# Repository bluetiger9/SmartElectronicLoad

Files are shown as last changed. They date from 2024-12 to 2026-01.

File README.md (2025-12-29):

# SmartElectronicLoad
A smart electronic load

## Component Selection

1. Current Sense Amplifier OpAmp:
   - amplifies the voltage drop from the current sense resistors
   - low input offset (<=1mV, lower is better) - offset is amplified with the same amount as the sense current
   - high gain bandwidth product (>=5-10MHz, higher is better) - can limit the overall bandwidth of the load - for ex. 5MHz GBP with 10x amplification results in a 0.5Mhz effective bandwidth
   - input and output must go down to negative rail (0V)
   - input and output may not go up to the positive rail (3V3/12V) - in this case current range is reduced according to the upper limits
   - supply: 0-3V3 (or 0-12V)

2. Load Set OpAmp:
   - controls the gate of the load MOSFETs
   - input and output must go down to the negative rail (0V)
   - gain bandwidth product (>=1MHz) - can limit the overall bandwidth of the load
   - supply: 0-12V

3. Voltage Sense Buffer / Current Sense Buffer OpAmps
   - acts as a buffer for the voltage sense signals
   - input and output must go down to the negative rail (0V)
   - input and output may not go up to the positive rail (3V3/12V) - in this case voltage / current sense ranges are reduces accordingly
   - supply: 0-3V3 (or 0-12V)

4. DAC Buffer OpAmp
   - acts as a buffer for the DAC output
   - input and output must go down to the negative rail (0V)
   - input and output may not go up to the positive rail (3V3/12V) - in this case current range is reduced according to the upper limits
   - supply: 0-3V3 (or 0-12V)

5. MOSFET-s
   - acts as the active dissipates power element
   - N-channel MOSFET in TO-247 or TO-220 package
   - thermal resistance (lower is better) drive heat dissipation capacity
   - switching speed can affect the overall load bandwidth
   - drain source voltage limits the maximum voltage of the load
   - ON state resistance limits the maximum current at low voltages
   - can be in isolated or non-isolated package - non-isolated need additional parts to avoid exposing the load voltage on the heat sink

6. Current Sense Resistor
   - used to measure the current dissipated by the load
   - should be in the range of 5mV-100mΩ - resistor value in combination with multiplication factor gives the current range of the load - ex. 10mΩ + 10x (@3.3V) results in a 0-33A range (per channel)
   - SMD-2512 package
   - two resistors can be placed in parallel to the lower heat dissipation (which causes drift)

7. ESP32 SoC
   - the "brain" of the load
   - ESP32-S3-WROOM-1 modules (or ESP32-S2-SOLO-2, not recommended as it only has one core, and the built in DAC is no longer used)
   - 4MB+ flash, optional PSRAM (Quad SPI only - Octal SPI variants disable some GPIO pins)

## Bandwidth / Stability Tunning:
1. C1/R9 (and C2/R10) sets the overall bandwidth of the load
   - ex. 330Ω with 4.7nF results in a bandwidth of a ~100kHz
   - bandwidth can be increased by changing C1/C2 (or R9/R10) - ex 1nF achieves a bandwidth ~480kHz
     (*note: the current sense and load set OpAmps must keep up)

2. R65 (and R69) sets the MOSFETs gate current
   - default value is 10Ω
   - in case of oscillations, changing this resistor to a higher (ex. 47Ω) or lower (?) value (ex. 1Ω) may help stabilizing the load

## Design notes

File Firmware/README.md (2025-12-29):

# Smart Electronic Load - Firmware

The firmware of the Smart Electronic Load is based on PlatformIO. It uses the ESP32 cores from pioarduino.

Features:
- RTOS based control loop
- Continuous ADC reads
- Web Server with API, and a simple UI
- OTA updates
- etc.

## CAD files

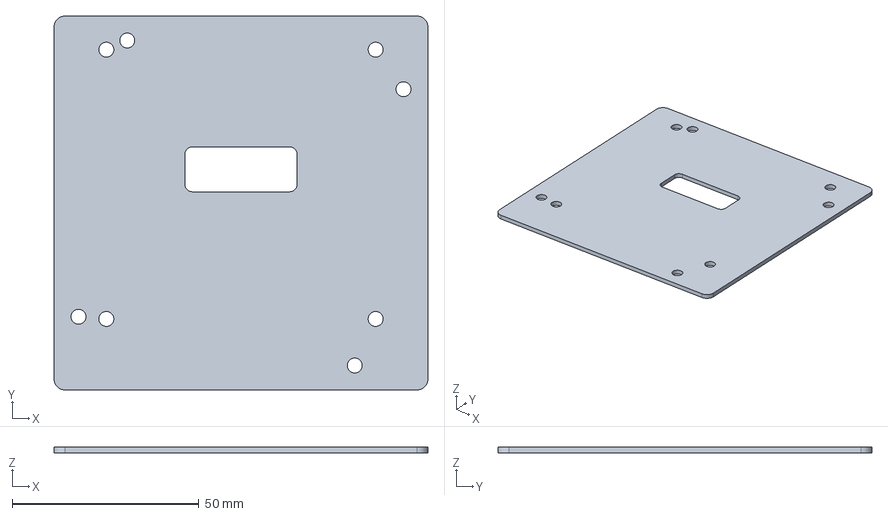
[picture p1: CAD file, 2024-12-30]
FreeCAD/ElectronicLoad.FCStd
100.0 x 100.0 x 1.60 mm

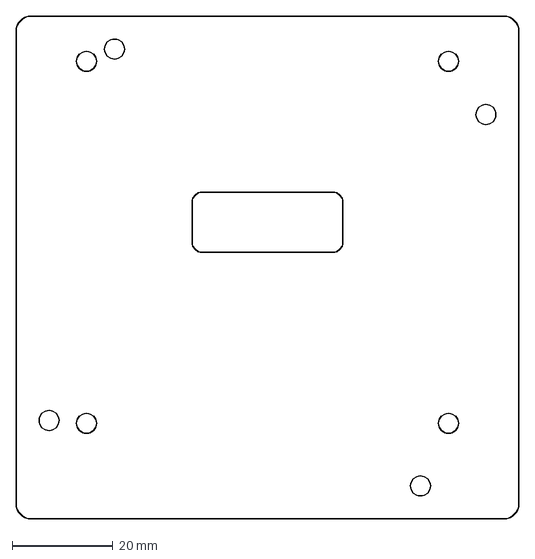
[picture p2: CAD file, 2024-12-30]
FreeCAD/ElectronicLoad-Outline.dxf
100.0 x 100.0 mm

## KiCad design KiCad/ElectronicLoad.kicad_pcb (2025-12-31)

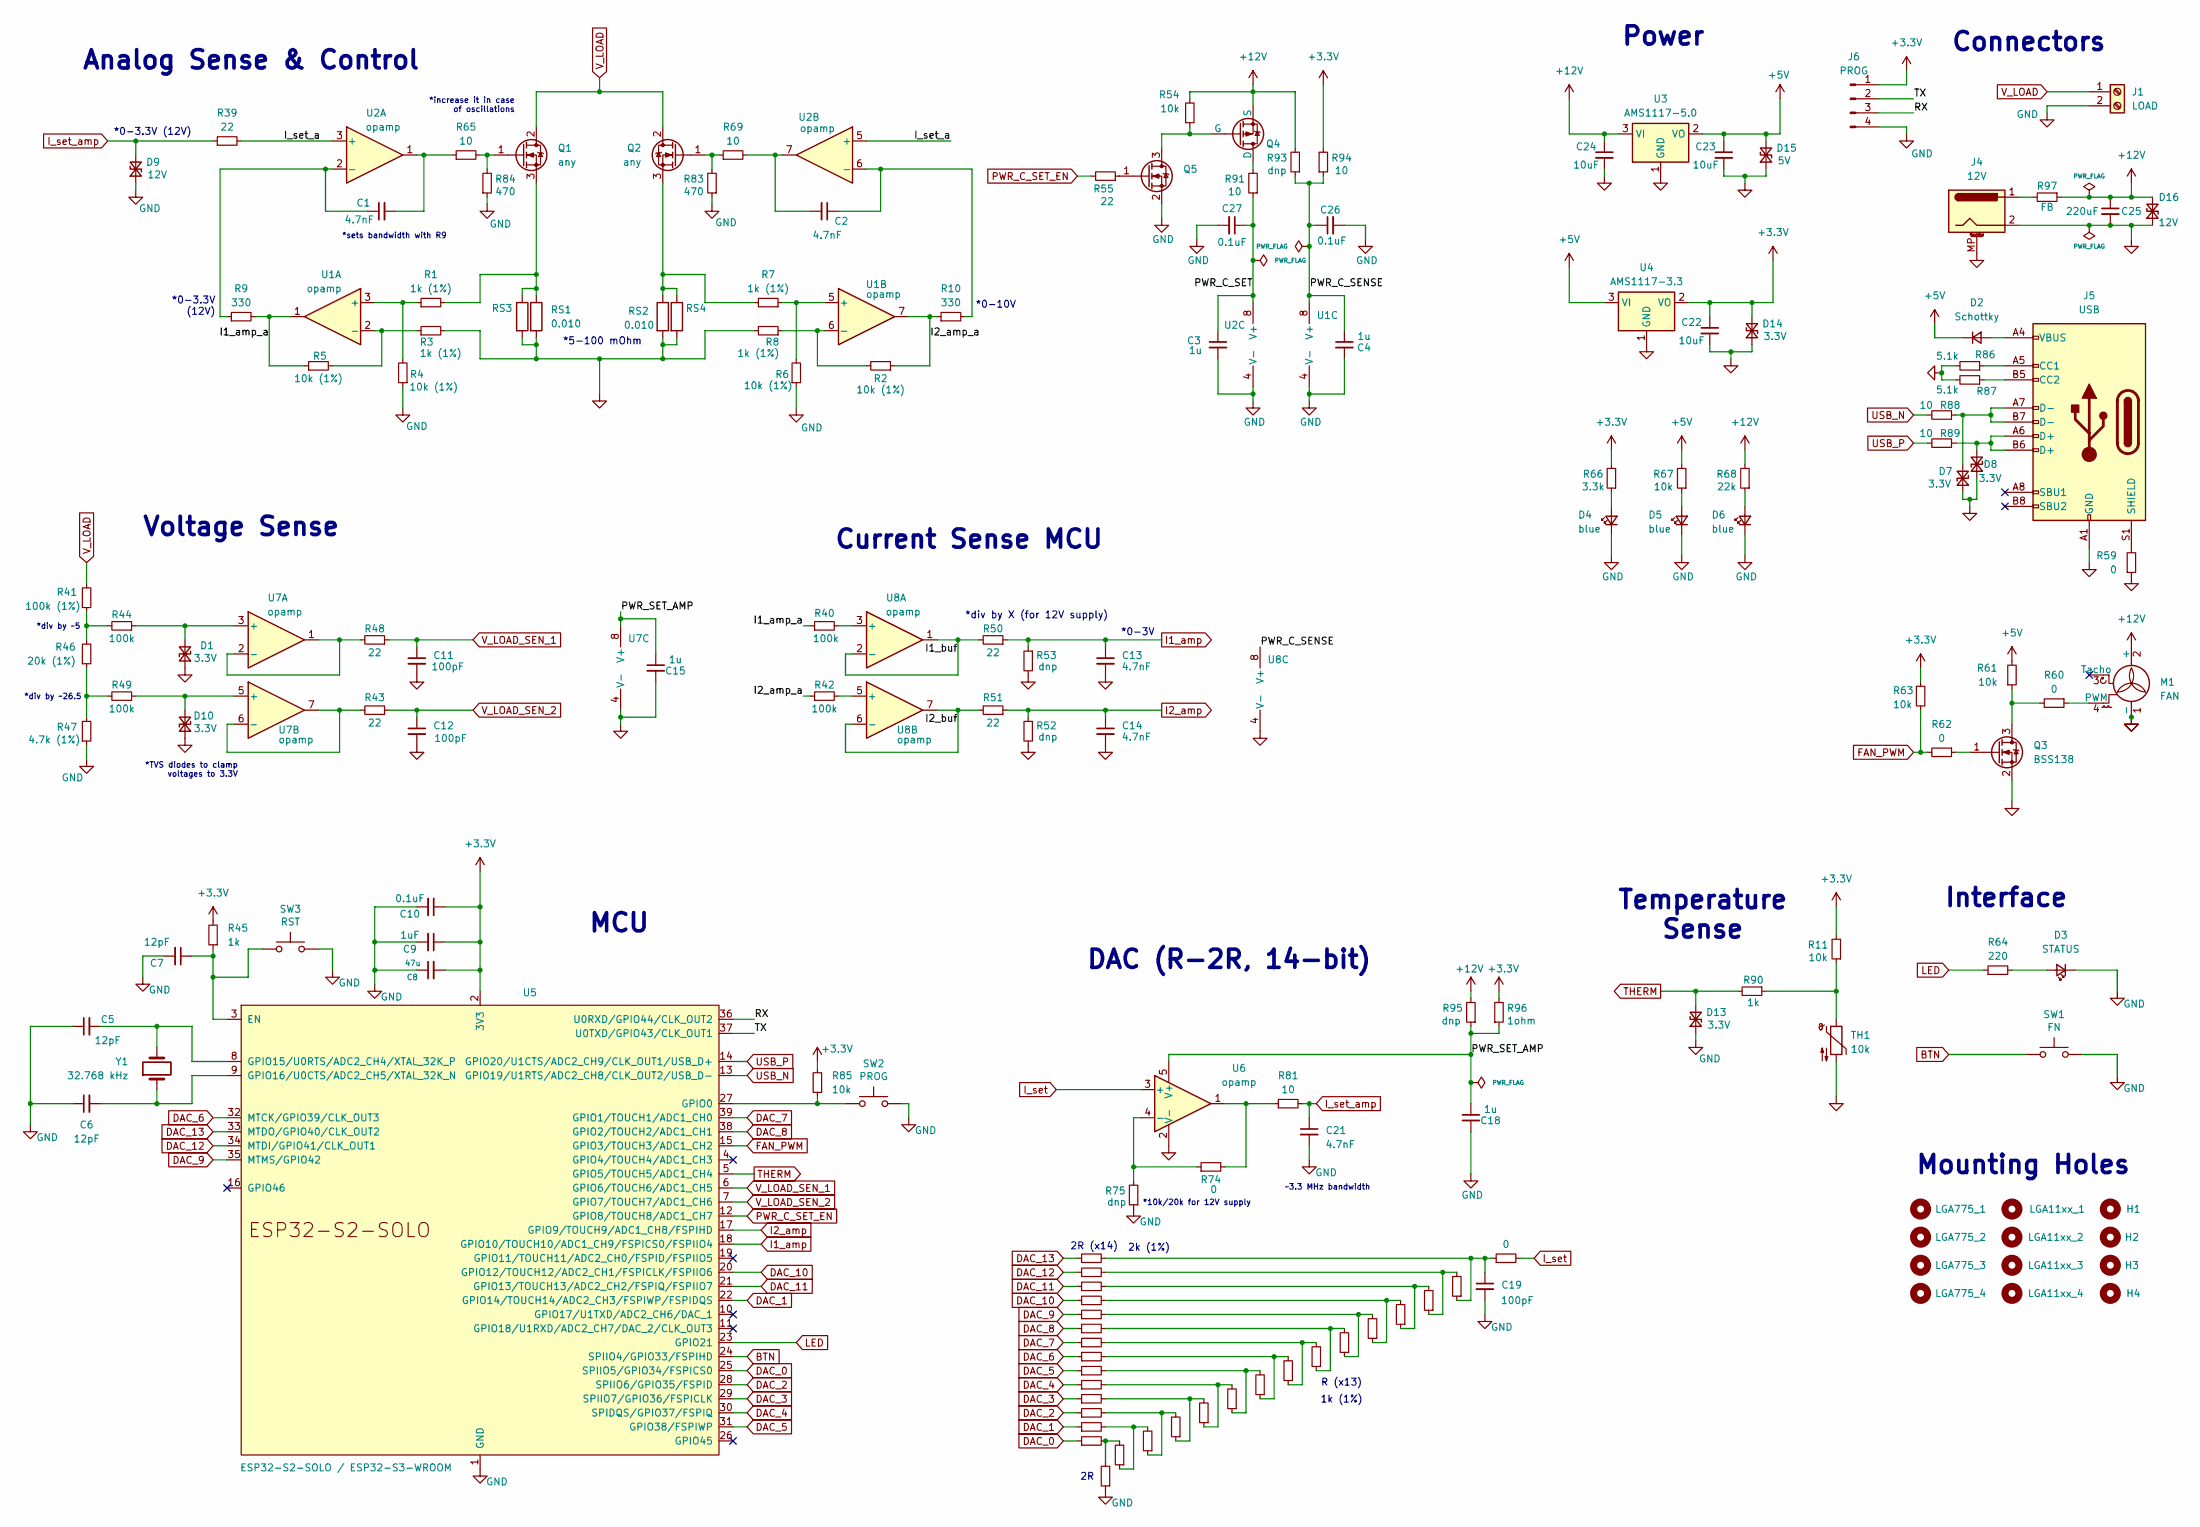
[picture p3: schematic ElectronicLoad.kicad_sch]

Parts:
C1, C2, C13, C14, C21: 4.7nF; C_0603_1608Metric
C3, C4, C15, C18: 1u; C_0603_1608Metric
C5, C6: 12pF; C_0603_1608Metric
C7: 12pF; C_0805_2012Metric
C8: 47u; C_0805_2012Metric
C9: 1uF; C_0805_2012Metric
C10, C26, C27: 0.1uF; C_0805_2012Metric
C11, C12, C19: 100pF; C_0603_1608Metric
C22, C23, C24: 10uF; C_0805_2012Metric
C25: 220uF; C_Elec_6.3x7.7
D1, D7, D8, D10, D13: 3.3V; D_SOD-323_HandSoldering
D2: Schottky; D_SOD-123
D3: STATUS; LED_0805_2012Metric
D4, D5, D6: blue; LED_0805_2012Metric
D9: 12V; D_SOD-323_HandSoldering
D14: 3.3V; D_SOD-123
D15: 5V; D_SOD-123
D16: 12V; D_SOD-123
H1, H2, H3, H4: MountingHole; MountingHole_4.3mm_M4
J1: LOAD; Terminal-Block-7-screw
J4: 12V; BarrelJack_Horizontal
J5: USB; USB_C_Receptacle_G-Switch_GT-USB-7010ASV
J6: PROG; PinHeader_1x04_P2.54mm_Vertical
LGA11xx_1, LGA11xx_2, LGA11xx_3, LGA11xx_4, LGA775_1, LGA775_2, LGA775_3, LGA775_4: MountingHole; MountingHole_4mm
M1: FAN; FanPinHeader_1x04_P2.54mm_Vertical
Q1, Q2: any; TO-247-220
Q3, Q5: BSS138; SOT-23
Q4: PMOS; SOT-23
R1, R3, R7, R8, R25, R26, R27, R28, R29, R30, R31, R32, R33, R34, R35, R36, R37: 1k (1%); R_0603_1608Metric
R2, R4, R5, R6: 10k (1%); R_0603_1608Metric
R9, R10: 330; R_0603_1608Metric
R11, R54, R61, R63, R67, R85: 10k; R_0805_2012Metric
R12, R13, R14, R15, R16, R17, R18, R19, R20, R21, R22, R23, R24, R38, R201: 2k (1%); R_0603_1608Metric
R39, R43, R48, R50, R51: 22; R_0603_1608Metric
R40, R42, R44, R49: 100k; R_0603_1608Metric
R41: 100k (1%); R_0603_1608Metric
R45, R90: 1k; R_0805_2012Metric
R46: 20k (1%); R_0603_1608Metric
R47: 4.7k (1%); R_0603_1608Metric
R52, R53, R75: dnp; R_0603_1608Metric
R55: 22; R_0805_2012Metric
R59, R60, R62: 0; R_0805_2012Metric
R64: 220; R_0805_2012Metric
R65, R69, R81, R88, R89: 10; R_0603_1608Metric
R66: 3.3k; R_0805_2012Metric
R68: 22k; R_0805_2012Metric
R70, R74: 0; R_0603_1608Metric
R83, R84: 470; R_0603_1608Metric
R86, R87: 5.1k; R_0603_1608Metric
R91, R94: 10; R_0805_2012Metric
R93, R95: dnp; R_0805_2012Metric
R96: 1ohm; R_0805_2012Metric
R97: FB; R_0805_2012Metric
RS1, RS2: 0.010; R_2512_6332Metric
RS3, RS4: 0.001; R_2512_6332Metric
SW1: FN; SW_SPST_TL3342
SW2: PROG; SW_SPST_TL3342
SW3: RST; SW_SPST_TL3342
TH1: 10k; PinHeader_1x02_P2.00mm_Vertical
U1, U2, U7, U8: opamp; SOIC-8_3.9x4.9mm_P1.27mm
U3: AMS1117-5.0; SOT-223-3_TabPin2
U4: AMS1117-3.3; SOT-223-3_TabPin2
U5: ESP32-S2-SOLO / ESP32-S3-WROOM; ESP32-S2-SOLO
U6: opamp; SOT-23-5
Y1: 32.768 kHz; Crystal_SMD_3215-2Pin_3.2x1.5mm

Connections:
+3.3V: C8.2, C9.1, C10.1, C22.1, D14.2 (A2), J6.1, R11.2, R45.2, R63.1, R66.2, R85.2, R94.2, R96.2, U4.2 (VO), U5.2 (3V3)
+5V: C23.1, D2.1 (K), D15.2 (A2), R61.2, R67.2, U3.2 (VO), U4.3 (VI)
+12V: C24.1, C25.1, D16.2 (A2), M1.2 (+), Q4.3 (S), R54.2, R68.2, R93.2, R95.2, R97.1, U3.3 (VI)
/I1_amp_a: R5.1, R9.2, R40.1, U1.1
/I1_buf: R50.2, U8.1, U8.2 (-)
/I2_amp_a: R2.1, R10.1, R42.1, U1.7
/I2_buf: R51.2, U8.6 (-), U8.7
/I_set_a: R39.2, U2.3 (+), U2.5 (+)
/PWR_C_SENSE: C4.1, C26.1, R93.1, R94.1, U1.8 (V+), U8.8 (V+)
/PWR_C_SET: C3.1, C27.1, R91.1, U2.8 (V+)
/PWR_SET_AMP: C15.1, C18.1, R95.1, R96.1, U6.5 (V+), U7.8 (V+)
/RX: J6.3, U5.36 (U0RXD/GPIO44/CLK_OUT2)
/TX: J6.2, U5.37 (U0TXD/GPIO43/CLK_OUT1)
BTN: SW1.1, U5.24 (SPIIO4/GPIO33/FSPIHD)
DAC_0: R24.1, U5.25 (SPIIO5/GPIO34/FSPICS0)
DAC_1: R23.1, U5.22 (GPIO14/TOUCH14/ADC2_CH3/FSPIWP/FSPIDQS)
DAC_2: R22.1, U5.28 (SPIIO6/GPIO35/FSPID)
DAC_3: R21.1, U5.29 (SPIIO7/GPIO36/FSPICLK)
DAC_4: R20.1, U5.30 (SPIDQS/GPIO37/FSPIQ)
DAC_5: R19.1, U5.31 (GPIO38/FSPIWP)
DAC_6: R18.1, U5.32 (MTCK/GPIO39/CLK_OUT3)
DAC_7: R17.1, U5.39 (GPIO1/TOUCH1/ADC1_CH0)
DAC_8: R16.1, U5.38 (GPIO2/TOUCH2/ADC1_CH1)
DAC_9: R15.1, U5.35 (MTMS/GPIO42)
DAC_10: R14.1, U5.20 (GPIO12/TOUCH12/ADC2_CH1/FSPICLK/FSPIIO6)
DAC_11: R13.1, U5.21 (GPIO13/TOUCH13/ADC2_CH2/FSPIQ/FSPIIO7)
DAC_12: R12.1, U5.34 (MTDI/GPIO41/CLK_OUT1)
DAC_13: R201.1, U5.33 (MTDO/GPIO40/CLK_OUT2)
FAN_PWM: R62.2, R63.2, U5.15 (GPIO3/TOUCH3/ADC1_CH2)
GND: C3.2, C4.2, C5.1, C6.1, C7.2, C8.1, C9.2, C10.2, C11.2, C12.2, C13.2, C14.2, C15.2, C18.2, C19.2, C21.2, C22.2, C23.2, C24.2, C25.2, C26.2, C27.2, D1.1 (A1), D3.1 (K), D4.1 (K), D5.1 (K), D6.1 (K), D7.1 (A1), D8.1 (A1), D9.1 (A1), D10.1 (A1), D13.1 (A1), D14.1 (A1), D15.1 (A1), D16.1 (A1), J1.2, J4.2, J4.MP (MountPin), J5.A1 (GND), J5.A12 (GND), J5.B1 (GND), J5.B12 (GND), J6.4, M1.1 (-), Q3.2 (S), Q5.2 (S), R3.2, R4.1, R6.1, R8.2, R38.1, R47.1, R52.2, R53.2, R59.1, R75.1, R83.1, R84.1, R86.2, R87.2, RS1.2, RS2.2, RS3.2, RS4.2, SW1.2, SW2.2, SW3.2, TH1.2, U1.4 (V-), U2.4 (V-), U3.1 (GND), U4.1 (GND), U5.1 (GND), U5.40 (GND), U5.41 (GND), U6.2 (V-), U7.4 (V-), U8.4 (V-)
I1_amp: C13.1, R50.1, R53.1, U5.18 (GPIO10/TOUCH10/ADC1_CH9/FSPICS0/FSPIIO4)
I2_amp: C14.1, R51.1, R52.1, U5.17 (GPIO9/TOUCH9/ADC1_CH8/FSPIHD)
I_set: R70.2, U6.3 (+)
I_set_amp: C21.1, D9.2 (A2), R39.1, R81.2
LED: R64.1, U5.23 (GPIO21)
unnamed: C1.2, R65.1, U2.1
unnamed: C2.2, R69.2, U2.7
unnamed: C19.1, R37.1, R70.1, R201.2
unnamed: D1.2 (A2), R44.1, U7.3 (+)
unnamed: D2.2 (A), J5.A4 (VBUS), J5.A9 (VBUS), J5.B4 (VBUS), J5.B9 (VBUS)
unnamed: D3.2 (A), R64.2
unnamed: D4.2 (A), R66.1
unnamed: D5.2 (A), R67.1
unnamed: D6.2 (A), R68.1
unnamed: D7.2 (A2), J5.A7 (D-), J5.B7 (D-), R88.1
unnamed: D8.2 (A2), J5.A6 (D+), J5.B6 (D+), R89.1
unnamed: D10.2 (A2), R49.1, U7.5 (+)
unnamed: J4.1, R97.2
unnamed: J5.A5 (CC1), R86.1
unnamed: J5.B5 (CC2), R87.1
unnamed: J5.S1 (SHIELD), R59.2
unnamed: M1.4 (PWM), R60.1
unnamed: Q1.1 (G), R65.2, R84.2
unnamed: Q1.3 (S), R1.2, RS1.1, RS3.1
unnamed: Q2.1 (G), R69.1, R83.2
unnamed: Q2.3 (S), R7.2, RS2.1, RS4.1
unnamed: Q3.3 (D), R60.2, R61.1
unnamed: Q3.1 (G), R62.1
unnamed: Q4.1 (D), R91.2
unnamed: Q4.2 (G), Q5.3 (D), R54.1
unnamed: Q5.1 (G), R55.1
unnamed: R11.1, R90.1, TH1.1
unnamed: R12.2, R36.1, R37.2
unnamed: R13.2, R35.1, R36.2
unnamed: R14.2, R34.1, R35.2
unnamed: R15.2, R33.1, R34.2
unnamed: R16.2, R32.1, R33.2
unnamed: R17.2, R31.1, R32.2
unnamed: R18.2, R30.1, R31.2
unnamed: R19.2, R29.1, R30.2
unnamed: R20.2, R28.1, R29.2
unnamed: R21.2, R27.1, R28.2
unnamed: R22.2, R26.1, R27.2
unnamed: R23.2, R25.1, R26.2
unnamed: R24.2, R25.2, R38.2
unnamed: R41.1, R44.2, R46.2
unnamed: R46.1, R47.2, R49.2
unnamed: R74.2, R81.1, U6.1
unnamed: R1.1, R4.2, U1.3 (+)
unnamed: R3.1, R5.2, U1.2 (-)
unnamed: R6.2, R7.1, U1.5 (+)
unnamed: R2.2, R8.1, U1.6 (-)
unnamed: C1.1, R9.1, U2.2 (-)
unnamed: C2.1, R10.2, U2.6 (-)
unnamed: C7.1, R45.1, SW3.1, U5.3 (EN)
unnamed: R85.1, SW2.1, U5.27 (GPIO0)
unnamed: C5.2, U5.8 (GPIO15/U0RTS/ADC2_CH4/XTAL_32K_P), Y1.2
unnamed: C6.2, U5.9 (GPIO16/U0CTS/ADC2_CH5/XTAL_32K_N), Y1.1
unnamed: R74.1, R75.2, U6.4 (-)
unnamed: R48.2, U7.1, U7.2 (-)
unnamed: R43.2, U7.6 (-), U7.7
unnamed: R40.2, U8.3 (+)
unnamed: R42.2, U8.5 (+)
PWR_C_SET_EN: R55.2, U5.12 (GPIO8/TOUCH8/ADC1_CH7)
THERM: D13.2 (A2), R90.2, U5.5 (GPIO5/TOUCH5/ADC1_CH4)
USB_N: R88.2, U5.13 (GPIO19/U1RTS/ADC2_CH8/CLK_OUT2/USB_D-)
USB_P: R89.2, U5.14 (GPIO20/U1CTS/ADC2_CH9/CLK_OUT1/USB_D+)
V_LOAD: J1.1, Q1.2 (D), Q2.2 (D), R41.2
V_LOAD_SEN_1: C11.1, R48.1, U5.6 (GPIO6/TOUCH6/ADC1_CH5)
V_LOAD_SEN_2: C12.1, R43.1, U5.7 (GPIO7/TOUCH7/ADC1_CH6)

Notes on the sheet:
Temperature Sense
Analog Sense & Control
Mounting Holes
*0-10V
Connectors
Interface
*5-100 mOhm
*sets bandwidth with R9
*0-3.3V (12V)
R (x13)
~3.3 MHz bandwidth
*0-3V
2k (1%)
*TVS diodes to clamp voltages to 3.3V
*div by ~26.5
*div by X (for 12V supply)
Power
*increase it in case of oscillations
1k (1%)
*10k/20k for 12V supply
Current Sense MCU
*0-3.3V (12V)
*div by ~5
2R (x14)
DAC (R-2R, 14-bit)
MCU
Voltage Sense

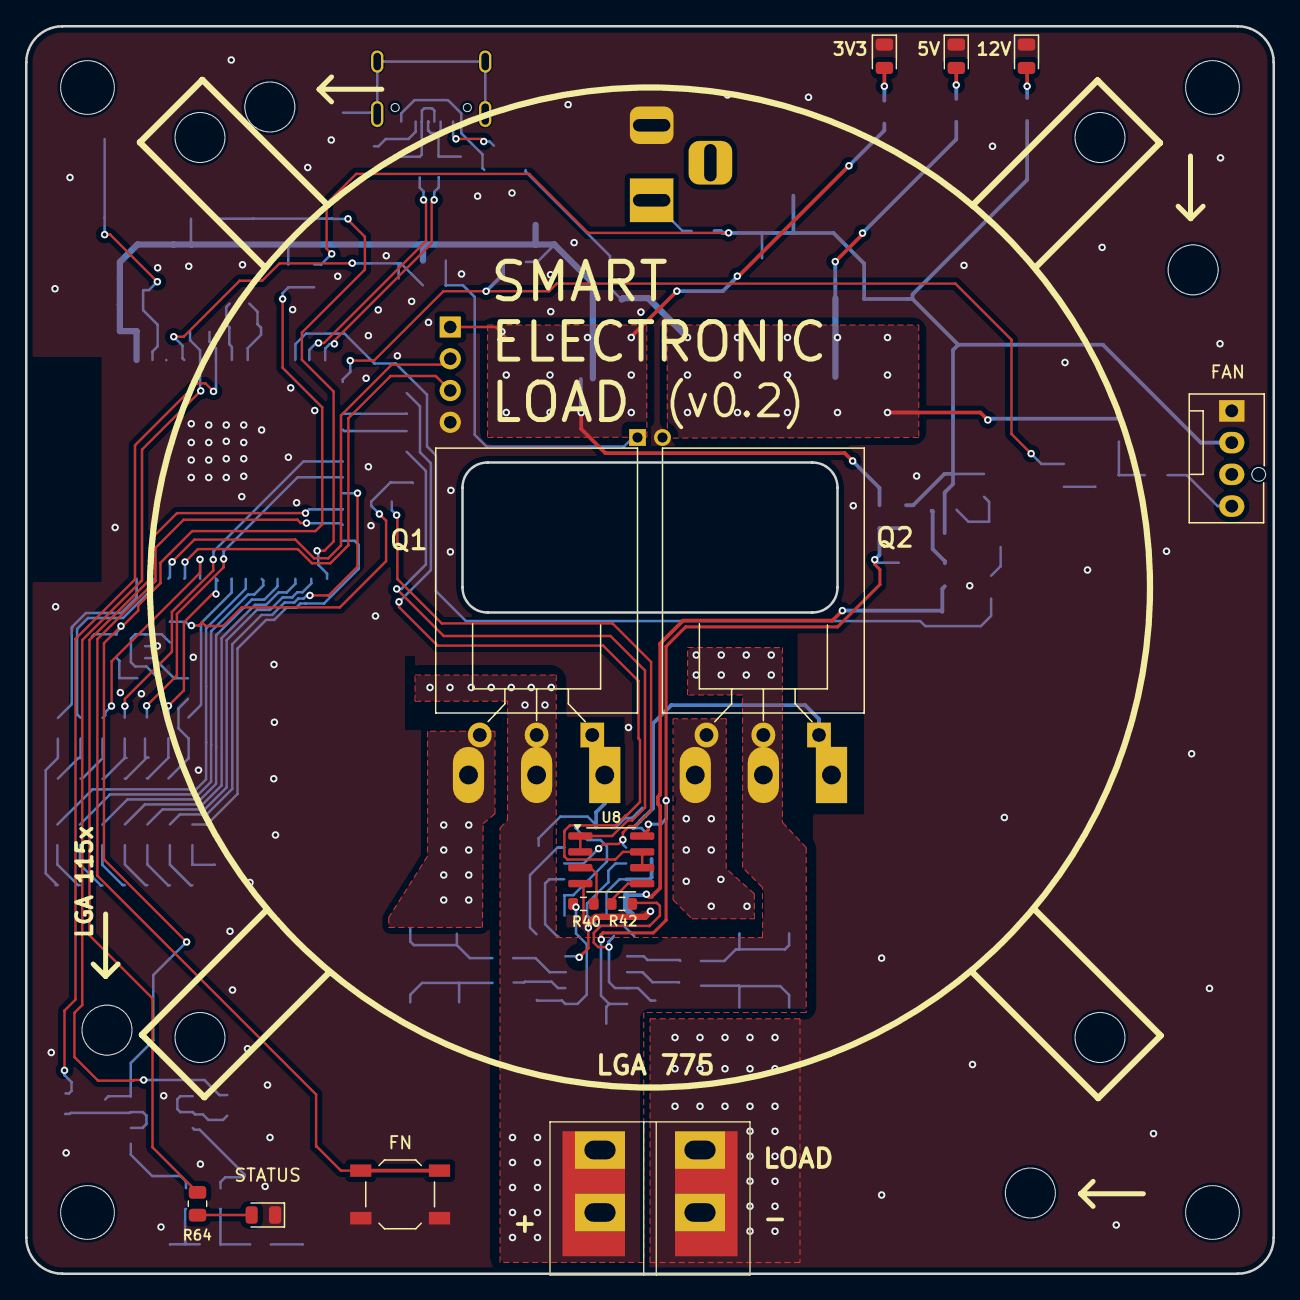
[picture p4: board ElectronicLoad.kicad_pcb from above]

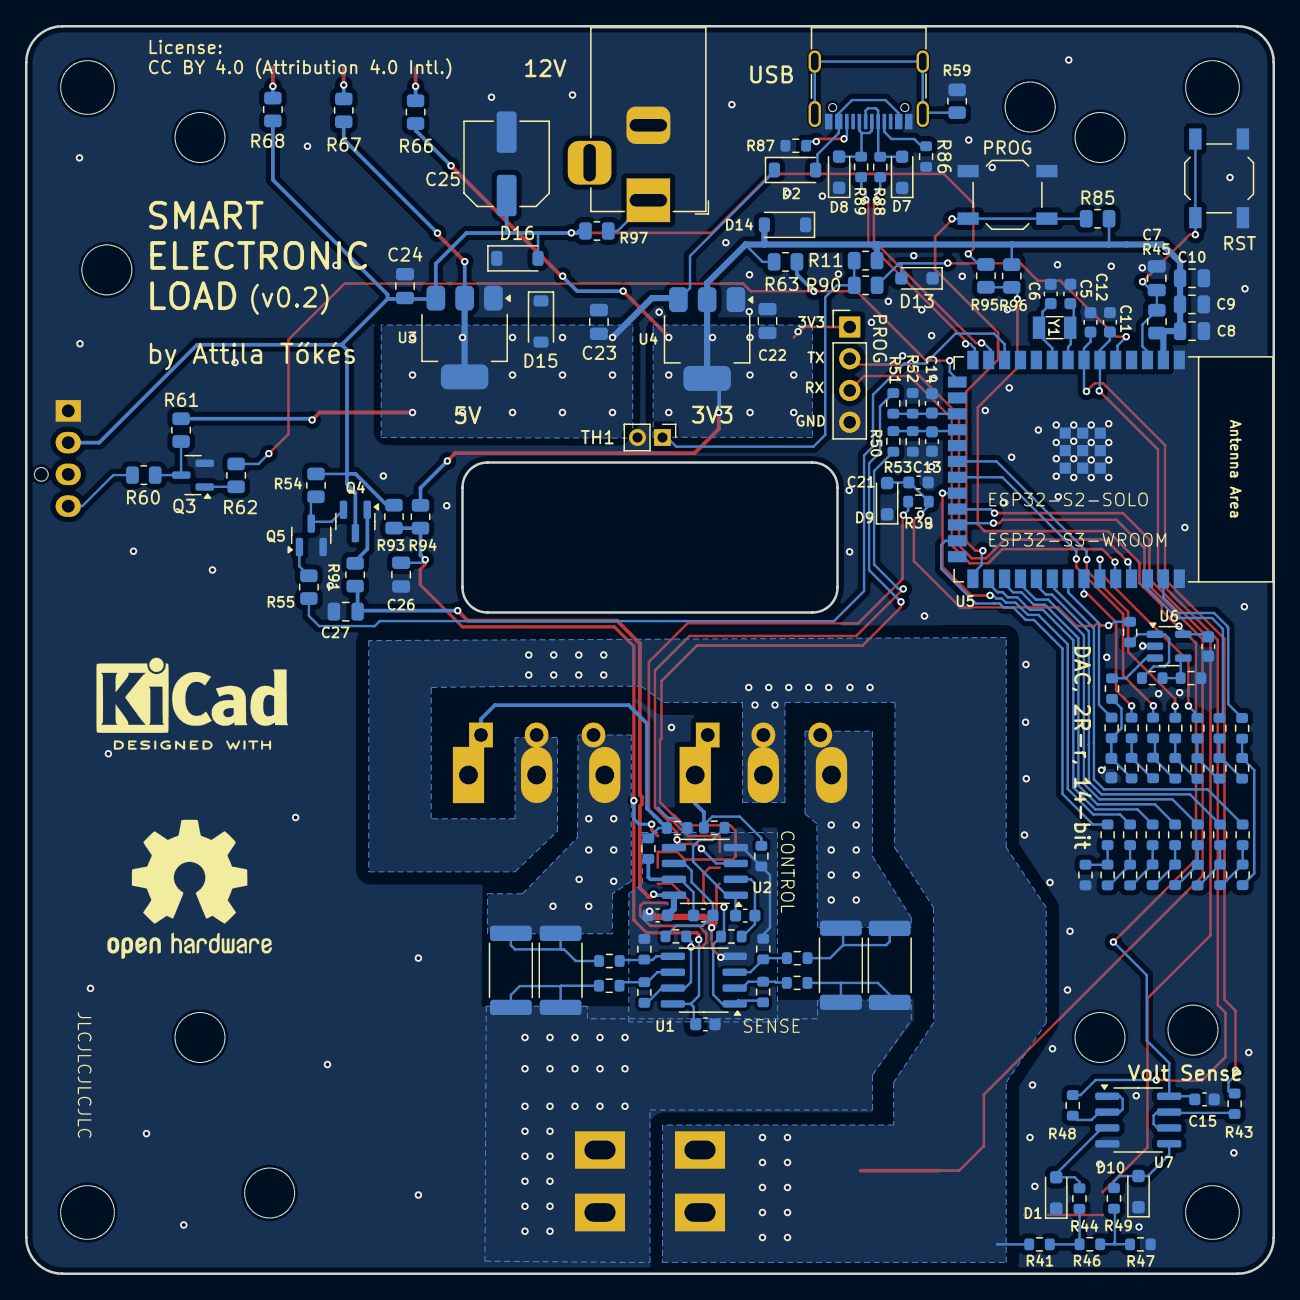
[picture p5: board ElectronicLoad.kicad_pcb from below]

Board: 2 copper layers, 99.8 x 99.8 mm, 162 parts (137 on the bottom side), 100 nets.

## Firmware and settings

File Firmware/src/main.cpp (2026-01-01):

/*
 * Copyright (c) 2025 by Attila Tőkés.
 *
 * Licence: MIT
 */
#include <Arduino.h>
#include <EEPROM.h>
#include <Adafruit_TinyUSB.h>

#include "hal/gpio_hal.h"

#include "dac.h"
#include "adc.h"
#include "fan.h"
#include "load.h"
#include "web.h"
#include "wifi.h"
#include "ota.h"
#include "srv.h"
#include "hw.h"
#include "shaper.h"

/* Pin Configuration */

const uint8_t PROG_PIN = 0;
const uint8_t LED_PIN = 21;

#if defined ESP32_S3
const uint8_t BTN_PIN = 47;
#elif defined ESP32_S2
const uint8_t BTN_PIN = 33;
#endif

const uint8_t VOLTAGE_SENSE_PIN_1 = 6;
const uint8_t VOLTAGE_SENSE_PIN_2 = 7;
const uint8_t CURRENT_SENSE_PIN_1 = 10;
const uint8_t CURRENT_SENSE_PIN_2 = 9;
const uint8_t TEMP_SENSE_PIN = 5;

const uint8_t FAN_PIN = 3;

const uint8_t LOAD_PWR_EN_PIN = 8;

#if defined ESP32_S3
const uint8_t DAC_PIN_0 = 48;
#elif defined ESP32_S2
const uint8_t DAC_PIN_0 = 34;
#endif

const uint8_t DAC_PIN_1 = 14;
const uint8_t DAC_PIN_2 = 35;
const uint8_t DAC_PIN_3 = 36;

const uint8_t DAC_PIN_4 = 37;
const uint8_t DAC_PIN_5 = 38;
const uint8_t DAC_PIN_6 = 39;
const uint8_t DAC_PIN_7 = 1;

const uint8_t DAC_PIN_8 = 2;
const uint8_t DAC_PIN_9 = 42;
const uint8_t DAC_PIN_10 = 12;
const uint8_t DAC_PIN_11 = 13;

const uint8_t DAC_PIN_12 = 41;
const uint8_t DAC_PIN_13 = 40;

const uint8_t NR_DAC_PINS = 14;

const uint8_t DAC_PINS[] = {
  DAC_PIN_0, DAC_PIN_1, DAC_PIN_2, DAC_PIN_3,
  DAC_PIN_4, DAC_PIN_5, DAC_PIN_6, DAC_PIN_7,
  DAC_PIN_8, DAC_PIN_9, DAC_PIN_10, DAC_PIN_11,
  DAC_PIN_12, DAC_PIN_13,
};

const uint8_t NR_ADC_PINS = 5;

const uint8_t ADC_PINS[] = {
  VOLTAGE_SENSE_PIN_1, CURRENT_SENSE_PIN_1, CURRENT_SENSE_PIN_2, TEMP_SENSE_PIN, VOLTAGE_SENSE_PIN_2
};

DAC dac(NR_DAC_PINS, DAC_PINS, 8);

ADC adc(NR_ADC_PINS, ADC_PINS);

Fan fan(FAN_PIN, 255);

Load load(dac, adc, fan, LOAD_PWR_EN_PIN);

Shaper shaper(load, 256);

Wireless wifi;

Service srv(dac, adc);

WebServer webServer(80, load, shaper, srv);

OTA ota;

#define EEPROM_SIZE 4

volatile uint8_t restartRequest = 0;
bool progMode = false;

// Global mutex
portMUX_TYPE mutex = portMUX_INITIALIZER_UNLOCKED;

/** Control loop task (priority=2) */
void controlLoopTask(void *pvParameters) {
  Serial.println("Control loop task started.");

  // begin ADC readings
  adc.begin();

  while (true) {
    for (uint64_t idx = 0; idx < 10000; idx++) {
      load.handle();
      shaper.handle();

      // GPIO.out_w1tc = ((uint32_t) 1 << LED_PIN);
      // GPIO.out_w1tc = ((uint32_t) 1 << LED_PIN);
      // GPIO.out_w1ts = ((uint32_t) 1 << LED_PIN);
    }

    if (restartRequest > 0) {
      taskENTER_CRITICAL(&mutex);

      if (restartRequest == 2) {
        // OTA restart
        EEPROM.begin(4);

        Serial.println("Setting EEPROM programming mode...");
        EEPROM.write(0, 1);
        EEPROM.commit();
      }

      Serial.println("Restarting ESP32...");
      Serial.flush();

      esp_restart();

      taskEXIT_CRITICAL(&mutex);
      return;
    }

    // TODO: why was a 1s delay here?
    //vTaskDelay(50 / portTICK_PERIOD_MS);
    vTaskDelay(50 / portTICK_PERIOD_MS);

    // let other tasks run
    taskYIELD();
  }
}

/** Critical control loop task (priority=10) */
void criticalControlLoopTask(void *pvParameters) {
  Serial.println("Critical control loop task started.");

  while (true) {
    // note: this will only run on request

    // sleep for now
    vTaskDelay(1000 / portTICK_PERIOD_MS);
  }
}

/** Control loop task handle */
TaskHandle_t controlLoopTaskHandle;

/** Critical control loop task handle */
TaskHandle_t criticalControlLoopTaskHandle;

void setup() {
  HardwareValues::init();

  Serial.begin(115200);

  pinMode(PROG_PIN, INPUT);
  pinMode(BTN_PIN, INPUT_PULLUP);
  pinMode(LED_PIN, OUTPUT);

  pinMode(FAN_PIN, OUTPUT);
  pinMode(LOAD_PWR_EN_PIN, OUTPUT);
  //analogWriteFrequency(FAN_PIN, 25000);

  fan.set(0.00);

  for (auto nr = 0; nr < NR_DAC_PINS; nr++) {
    pinMode(DAC_PINS[nr], OUTPUT);
  }

  for (auto nr = 0; nr < NR_ADC_PINS; nr++) {
    pinMode(ADC_PINS[nr], INPUT);
    //adcAttachPin(ADC_PINS[nr]); todo
  }

  EEPROM.begin(EEPROM_SIZE);

  int persProgMode = EEPROM.read(0);

  Serial.printf("EEPROM prog mode flag: %d\n", persProgMode);
  if (persProgMode > 0) {
    // prog mode requested
    progMode = true;
    EEPROM.write(0, 0); // Reset flag
    EEPROM.commit();
    Serial.println("Programming mode requested...");
  }

  if (progMode || digitalRead(BTN_PIN) == 0) {
    // enable prog mode
    progMode = true;
    Serial.println("Programming mode...");
  }

  // start WiFi
  wifi.begin();

  // Initialize LittleFS
  if (!LittleFS.begin()) {
    Serial.println("Failed to mount LittleFS");
    return;
  }

  Serial.println("Content:");
  File dir = LittleFS.open("/");
  File file = dir.openNextFile();
  char buf[1024];
  while (file) {
     Serial.println(file.name());
     file = dir.openNextFile();
  }

  // start the web server
  webServer.begin();

  if (progMode) {
    ota.begin();
    return;
  }

  // create control loop task
  Serial.println("Creating control loop and critical control loop tasks...");

  // wrap task creation in a critical section
  taskENTER_CRITICAL(&mutex);

  // create control loop task
  auto retval = xTaskCreate(
      controlLoopTask,        // Task function
      "ControlLoopTask",      // Name of the task
      2048,                   // Stack size
      NULL,                   // Task parameter
      1,                      // Priority (higher than loop()'s priority 1)
      &controlLoopTaskHandle  // Task handle
  );

  if (retval != pdPASS) {
    Serial.println("Creation of control loop task FAILED!");
    return;
  }

  // create critical control loop task
  retval = xTaskCreate(
      criticalControlLoopTask,        // Task function
      "CriticalControlLoopTask",      // Name of the task
      2048,                           // Stack size
      NULL,                           // Task parameter
      5,                              // Priority (higher than loop()'s priority 1)
      &criticalControlLoopTaskHandle  // Task handle
  );

  if (retval != pdPASS) {
    Serial.println("Creation of critical control loop task FAILED!");
    return;
  }

  // end of critical section
  taskEXIT_CRITICAL(&mutex);

  if (!TinyUSBDevice.isInitialized()) {
    TinyUSBDevice.begin(0);
  }

}

void loop() {
  if (progMode) {
    ota.handle();
  }

}

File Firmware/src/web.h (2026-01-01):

/*
 * Copyright (c) 2025 by Attila Tőkés.
 *
 * Licence: MIT
 */
#ifndef WEB_H
#define WEB_H

#include <Arduino.h>
#include <WiFi.h>
#include <AsyncTCP.h>
#include <ESPAsyncWebServer.h>
#include <LittleFS.h>
#include "load.h"
#include "shaper.h"
#include "srv.h"

/** Web / HTTP Server */
class WebServer {

public:

  /**Instantiates the Web Server. */
  WebServer(const uint16_t port, Load& load, Shaper &shaper, Service &srv)
    : server(AsyncWebServer(port)), load(load), shaper(shaper), srv(srv) {

      DefaultHeaders::Instance().addHeader("Access-Control-Allow-Origin", "*");
      DefaultHeaders::Instance().addHeader("Access-Control-Allow-Methods", "GET, POST, PUT");
      DefaultHeaders::Instance().addHeader("Access-Control-Allow-Headers", "Content-Type");

      const WebServer *that = this;

      /** API Handlers **/

      // Voltage get
      this->server.on("/api/voltage", HTTP_GET, [this](AsyncWebServerRequest *request) {
        this->handleApiGetVoltage(request);
      });

      // Current get
      this->server.on("/api/current", HTTP_GET, [this](AsyncWebServerRequest *request) {
        this->handleApiGetCurrent(request);
      });

      // Temperature get
      this->server.on("/api/temperature", HTTP_GET, [this](AsyncWebServerRequest *request) {
        this->handleApiGetTemperature(request);
      });

      // Current set
      this->server.on("/api/current", HTTP_PUT, [this](AsyncWebServerRequest *request) {}, NULL, [this](AsyncWebServerRequest *request, uint8_t *data, size_t len, size_t index, size_t total) {
        this->handleApiSetCurrent(request, data, len, index, total);
      });

      // Power set
      this->server.on("/api/power", HTTP_PUT, [this](AsyncWebServerRequest *request) {}, NULL, [this](AsyncWebServerRequest *request, uint8_t *data, size_t len, size_t index, size_t total) {
        this->handleApiSetPower(request, data, len, index, total);
      });

      // Resistance set
      this->server.on("/api/resistance", HTTP_PUT, [this](AsyncWebServerRequest *request) {}, NULL, [this](AsyncWebServerRequest *request, uint8_t *data, size_t len, size_t index, size_t total) {
        this->handleApiSetResistance(request, data, len, index, total);
      });

      // Fan Speed set
      this->server.on("/api/fan", HTTP_PUT, [this](AsyncWebServerRequest *request) {}, NULL, [this](AsyncWebServerRequest *request, uint8_t *data, size_t len, size_t index, size_t total) {
        this->handleApiSetFanSpeed(request, data, len, index, total);
      });

      // Load enable
      this->server.on("/api/enable", HTTP_PUT, [this](AsyncWebServerRequest *request) {
        this->handleApiLoadEnable(request, true);
      });

      // Load disable
      this->server.on("/api/disable", HTTP_PUT, [this](AsyncWebServerRequest *request) {
        this->handleApiLoadEnable(request, false);
      });

      // Operating Mode set
      this->server.on("/api/mode", HTTP_PUT, [this](AsyncWebServerRequest *request) {}, NULL, [this](AsyncWebServerRequest *request, uint8_t *data, size_t len, size_t index, size_t total) {
        this->handleApiSetMode(request, data, len, index, total);
      });

      // Pulse (shaper)
      this->server.on("/api/shaper/pulse", HTTP_POST, [this](AsyncWebServerRequest *request) {}, NULL, [this](AsyncWebServerRequest *request, uint8_t *data, size_t len, size_t index, size_t total) {
        this->handleApiShaperPulse(request, data, len, index, total);
      });

      // State get
      this->server.on("/api/state", HTTP_GET, [this](AsyncWebServerRequest *request) {
        this->handleApiGetState(request);
      });

      // Set over temperature limit
      this->server.on("/api/protections/over-temperature", HTTP_PUT, [this](AsyncWebServerRequest *request) {}, NULL, [this](AsyncWebServerRequest *request, uint8_t *data, size_t len, size_t index, size_t total) {
        this->handleApiSetOverTemperatureLimit(request, data, len, index, total);
      });

      // Set over current limit
      this->server.on("/api/protections/over-current", HTTP_PUT, [this](AsyncWebServerRequest *request) {}, NULL, [this](AsyncWebServerRequest *request, uint8_t *data, size_t len, size_t index, size_t total) {
        this->handleApiSetOverCurrentLimit(request, data, len, index, total);
      });

      // Set over voltage limit
      this->server.on("/api/protections/over-voltage", HTTP_PUT, [this](AsyncWebServerRequest *request) {}, NULL, [this](AsyncWebServerRequest *request, uint8_t *data, size_t len, size_t index, size_t total) {
        this->handleApiSetOverVoltageLimit(request, data, len, index, total);
      });

      // Set over current limit
      this->server.on("/api/protections/over-power", HTTP_PUT, [this](AsyncWebServerRequest *request) {}, NULL, [this](AsyncWebServerRequest *request, uint8_t *data, size_t len, size_t index, size_t total) {
        this->handleApiSetOverPowerLimit(request, data, len, index, total);
      });

      // Reset protections
      this->server.on("/api/protections/reset", HTTP_POST, [this](AsyncWebServerRequest *request) {
        this->handleApiResetProtections(request);
      });

      // Disable protections
      this->server.on("/api/protections/disable", HTTP_POST, [this](AsyncWebServerRequest *request) {
        this->handleApiDisableProtections(request);
      });

      // Enable protections
      this->server.on("/api/protections/enable", HTTP_POST, [this](AsyncWebServerRequest *request) {
        this->handleApiEnableProtections(request);
      });

      // Power auto-detect enable
      this->server.on("/api/power/auto-detect/enable",  HTTP_POST, [this](AsyncWebServerRequest *request) {
        this->handleApiSetPowerAutoDetect(request, true);
      });

      // Power auto-detect enable
      this->server.on("/api/power/auto-detect/disable",  HTTP_POST, [this](AsyncWebServerRequest *request) {
        this->handleApiSetPowerAutoDetect(request, false);
      });

      // Set over current limit
      this->server.on("/api/power/auto-detect/delay", HTTP_PUT, [this](AsyncWebServerRequest *request) {}, NULL, [this](AsyncWebServerRequest *request, uint8_t *data, size_t len, size_t index, size_t total) {
        this->handleApiSetPowerAutoDetectDelay(request, data, len, index, total);
      });

      /** Service / Test API Handler **/

      // DAC set
      this->server.on("/api/srv/dac/set", HTTP_PUT, [this](AsyncWebServerRequest *request) {}, NULL, [this](AsyncWebServerRequest *request, uint8_t *data, size_t len, size_t index, size_t total) {
        this->handleApiSrvDacSet(request, data, len, index, total);
      });

      // DAC swipe
      this->server.on("/api/srv/dac/swipe", HTTP_POST, [this](AsyncWebServerRequest *request) {
        this->handleApiSrvDacSwipe(request);
      });

      // OTA restart
      this->server.on("/api/srv/ota/restart", HTTP_POST, [this](AsyncWebServerRequest *request) {
        this->handleApiSrvOtaRestart(request);
      });
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

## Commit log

2025-01-19 ESP32-S2 support + improved firmware
    [ElectronicLoad.kicad_pcb, ElectronicLoad.kicad_sch]
2025-04-06 Firmware update (USB)
    [ElectronicLoad.kicad_sch]
2025-11-30 rev0.2: remove DAC offset compensation and test connectors
    [ElectronicLoad.kicad_pcb, ElectronicLoad.kicad_sch]
2025-11-30 rev0.2: use only one Current Set line
    [ElectronicLoad.kicad_pcb, ElectronicLoad.kicad_sch]
2025-12-01 rev0.2: separate DAC10/11 lines from RX/TX
    [ElectronicLoad.kicad_pcb, ElectronicLoad.kicad_sch]
2025-12-01 rev0.2: remove MOSFET caps
    [ElectronicLoad.kicad_pcb, ElectronicLoad.kicad_sch]
2025-12-01 rev0.2: redesign the Voltage & (MCU) Current Sense circuits
    [ElectronicLoad.kicad_pcb, ElectronicLoad.kicad_sch]
2025-12-01 rev0.2: add duplicate current sense resistor footprint
    [ElectronicLoad.kicad_pcb, ElectronicLoad.kicad_sch]
2025-12-01 rev0.2: add disable MOSFET-s signal
    [ElectronicLoad.kicad_pcb, ElectronicLoad.kicad_sch]
2025-12-02 rev0.2: adjust component values
    [ElectronicLoad.kicad_pcb, ElectronicLoad.kicad_sch]
2025-12-29 rev 0.2 adjustments
    [ElectronicLoad.kicad_sch]
2025-12-29 constant power and constance resistance modes (+api)
2025-12-30 process ADC reading only when they are available
2025-12-30 over temperature/current/voltage/power protection (+api)
2025-12-30 auto enable/disable on power connect/disconnect (+api)
2025-12-31 rev 0.2 schematics + pcb adjustments
    [ElectronicLoad.kicad_pcb, ElectronicLoad.kicad_sch]
2025-12-31 basic calibration support

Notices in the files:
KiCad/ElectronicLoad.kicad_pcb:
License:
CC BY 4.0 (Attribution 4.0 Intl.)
